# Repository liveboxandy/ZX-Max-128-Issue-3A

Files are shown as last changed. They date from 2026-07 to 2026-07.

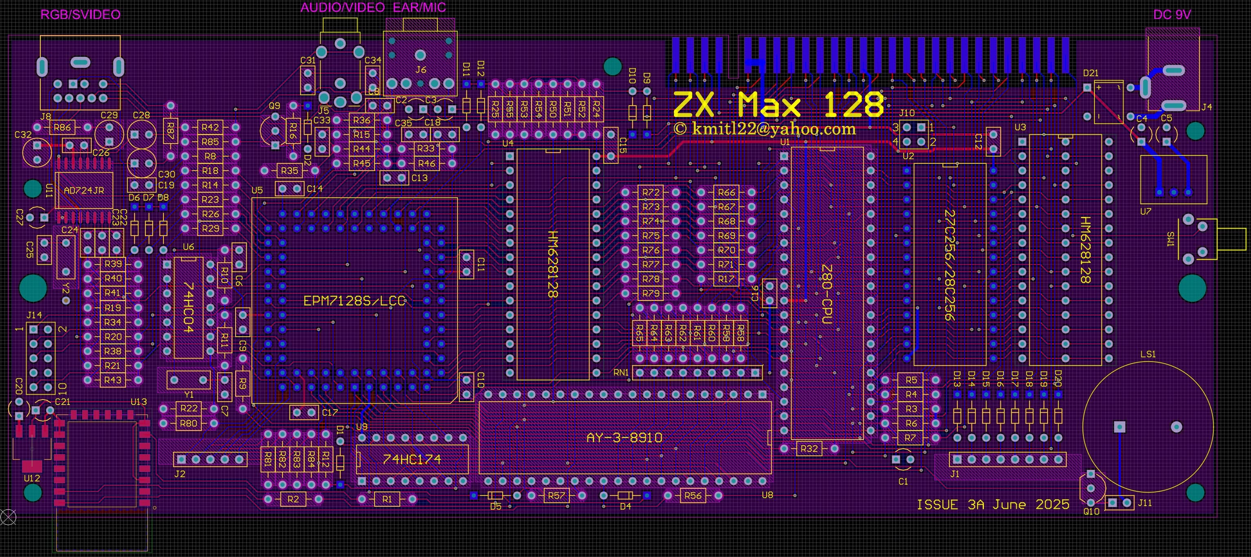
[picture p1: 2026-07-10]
ZX Max 128 Issue 3A June 2025.jpg

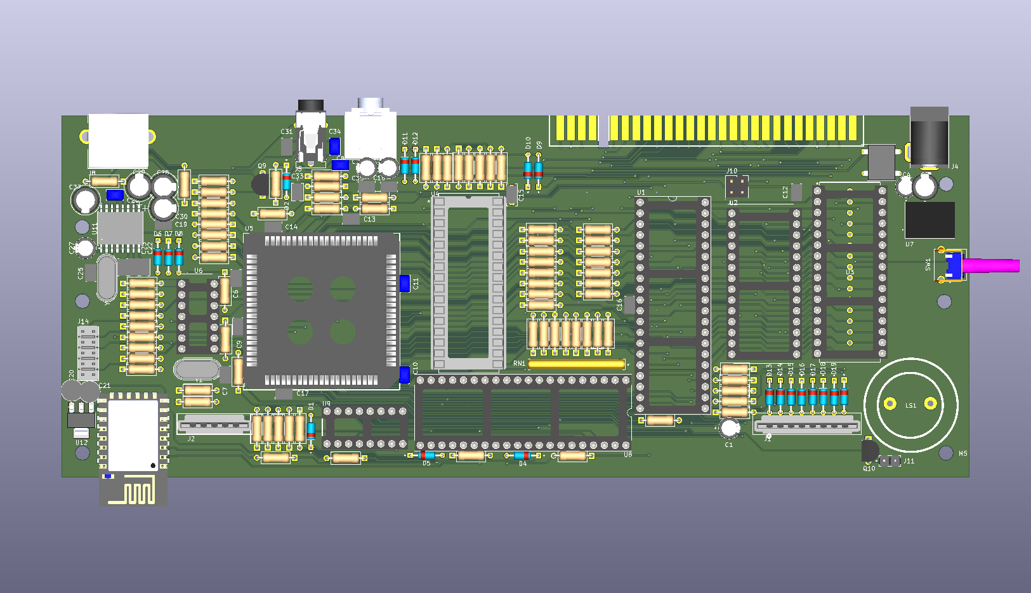
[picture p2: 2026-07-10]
ZX Max 128 Issue 3A PCB.png

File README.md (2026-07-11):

# ZX-Max-128-Issue-3A June 2025
KiCAD created files for the ZX Max 128 Issue 3A designed by DonSuperfo

This Kicad project has only been done so as to allow for a proper ibom that 
includes tracks and vias to be created.
I have tried to ensure that the footprints were located 
as close as possible to those in the original as well trying to follow 
the existing track and via locations. Some of the footprints that were 
downloaded from Digikey based on the parts in the official BOM do not fit 
exactly in their locations on the board. C15 is one example, I had to 
modify it's footprint to fit the pad dimensions. Some other capacitors also 
do not fit correctly but appear to be close enough.

As such, although I have tried to be as accurate as possible I would NOT 
use these gerbers to have a pcb manufactured without having another set of
eyes checking that the schematic that I have produced is correct to that 
produced by DonSuperfo and that the pcb data from Kicad reports no major errors 
with regards to copper tracing and via positions.

For the jumpers/connectors on the board,

J1 8 Way Keyboard Connector

J2 5 Way Keyboard Connector

J3 ZX Expansion Connector

J4 DC Input - can be any polarity. 

J5 Video is a TRRS, Tip-Video,RR-Left/Right, Screen-Ground.

J6 Ear/Mic. Wired as per ZX Spectrum 128K +3. TRS. Tip-Mic, Ring-Ear, Screen-Ground.

J7 Not Used

J8 SCART, mates with a Sega megadrive cable.

J9 Not Used

J10 EEPROM/UVEPROM selection, EEPROM 2-4/1-3, UVEPROM 2-1/4-3.

J11 Speaker On/Off

J12 Not Used

J13 Not Used

J14 JTAG for the EPM7128 wired as standard to an Altera device.

J15 Not Used

J16 Disable DivMMC, close = enable DivMMC, open = disable DivMMC or need to update program on U17

SW1 RESET

From information on the original website,

In order to make ACB output more balanced I would recommend following the -4.5dB 
panning law rule and make these updates:

R54, R55 = 470 Ohm
R51, R52 = 560 Ohm
R50, R53 = 330 Ohm

The ratio of 560 / 330 = 1.6969 is a close approximation of 1 / 10^(-4.5 / 20) = 1.6788. 
Also the resulting equivalent resistance is around 1000 Ohm which leads to less distortion on AY outputs.

mismatch between the value on the scheme and in the BOM for part R32 (INT)
on scheme it is 470R but in BOM 10k.
it looks like in BOM incorrect value.

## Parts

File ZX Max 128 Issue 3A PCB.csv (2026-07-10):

Source: | E:\Kicad\ZX Max 128 Issue 3\ZX Max 128 Issue 3 PCB.kicad_sch
Date: | 2026-07-10T17:57:36
Tool: | Eeschema 10.0.4
Generator: | C:\Program Files\KiCad\7.0\bin\scripting\plugins/bom_csv_grouped_by_value_with_fp.py
Component Count: | 162
Ref | Qnty | Value | Cmp name | Footprint | Description | Vendor | DNP
C1, C2, C3, C4, C20, C21, C27 | 7 | 10uF 25V | ECA-1EM100B | Mod:CAPPRD200W50D500H1100 | ECA-1EM100B - 10uF Aluminum Electrolytic Capacitors Radial
C5 | 1 | 22uF 16V | ECA-1EM100B | Mod:CAPPRD200W50D500H1100 | ECA-1EM100B - 10uF Aluminum Electrolytic Capacitors Radial
C6, C7 | 2 | 27pF | FG18C0G1H270JNT06 | Mod:CAPRB250W50L400T250H550
C8, C9, C10, C11, C12, C13, C14, C16, C17, C18, C22, C23, C24, C26, C31, C34 | 16 | 100nF | K104Z15Y5VF5TL2 | Mod:CAPRB250W50L400T250H550 | Vishay K 100nF Ceramic Multilayer Capacitor, 100 V dc, +85C, Y5V Dielectric, +80 %, -20 %
C15 | 1 | 100nF | K104Z15Y5VF5TL2 | Mod:Capacitor 3.8mm PItch | Vishay K 100nF Ceramic Multilayer Capacitor, 100 V dc, +85C, Y5V Dielectric, +80 %, -20 %
C19, C35 | 2 | 3n3 50V | K104Z15Y5VF5TL2 | Mod:CAPRB250W50L400T250H550 | Vishay K 100nF Ceramic Multilayer Capacitor, 100 V dc, +85C, Y5V Dielectric, +80 %, -20 %
C25 | 1 | 10pF | K104Z15Y5VF5TL2 | Mod:CAPRB250W50L400T250H550 | Vishay K 100nF Ceramic Multilayer Capacitor, 100 V dc, +85C, Y5V Dielectric, +80 %, -20 %
C28, C29, C30, C32 | 4 | 220uF 16V | 16YXJ220MT16.3X11 | Mod:CAP_YX_6P3X11_RUB
C33 | 1 | 10nF 50V | K104Z15Y5VF5TL2 | Mod:CAPRB250W50L400T250H550 | Vishay K 100nF Ceramic Multilayer Capacitor, 100 V dc, +85C, Y5V Dielectric, +80 %, -20 %
D1, D2, D4, D5, D6, D7, D8, D9, D10, D11, D12, D13, D14, D15, D16, D17, D18, D19, D20 | 19 | 1N4148 | 1N4148 | Mod:DIOAD753W49L380D172B | Diode 1N4148
D21 | 1 | DF02M | DF02M | Mod:DIP825W58P510L832H543Q4N | Bridge Rectifier DF02M 1A
J1 | 1 | 8 Pin FFC Connector | 5-520315-8 | Mod:55203155 | Connector FFC Socket 8 Pin
J2 | 1 | 5 Pin FFC Connector | 5-520315-5 | Mod:55203155 | Connector FFC Socket 5 Pin
J3 | 1 | ZX_48K_EDGE | ZX_48K_EDGE | Mod:ZX_BUS_B_TOP | ZX Spectrum 48K Edge Connector
J4 | 1 | PJ-002A | PJ-002A | Mod:CUI_PJ-002A
J5 | 1 | AV Jack | AudioJack3 | Mod:PJ-322A | AV Jack PJ-322
J6 | 1 | Connector Audio 3525N | SJ1-3525N | Mod:CUI_SJ1-3525N | Connector Audio 3525N
J8 | 1 | Connector 9 Pin Mini DIN | KMDGX-9S-BS-1 | Mod:KMDGX9SBS1 | Connector 9 Pin MiniDin
J10 | 1 | Conn_02x02_Odd_Even | Conn_02x02_Odd_Even | Connector_PinHeader_2.54mm:PinHeader_2x02_P2.54mm_Vertical | Generic connector, double row, 02x02, odd/even pin numbering scheme (row 1 odd numbers, row 2 even numbers), script generated (kicad-library-utils/schlib/autogen/connector/)
J11 | 1 | CON2 | M20-9990246 | Mod:HARWIN_M20-9990246 | Header 2x1
J14 | 1 | Header 5x2 | 10129381-910002BLF | Mod:AMPHENOL_10129381-910002BLF | Header 5x2
LS1 | 1 | Speaker | Speaker | Mod:Speaker | Speaker
Q9, Q10 | 2 | Transistor BC548 | BC548BTA | Mod:BC548BTA
R1, R2, R7, R9, R12, R32, R36, R56, R57, R58, R59, R60, R61, R62, R63, R64, R65, R66, R67, R68, R69, R70, R71, R72, R73, R74, R75, R76, R77, R78, R79 | 31 | 470R | CF14JT470R | Mod:STA_CF14_STP | 470R
R3, R4, R5, R6, R15, R16, R24, R25, R35, R45, R80, R81, R82, R83, R84 | 15 | 10K0 | CF14JT10K0 | Mod:STA_CF14_STP | Resistor 10K0
R8 | 1 | 2K70 | CF14JT2K70 | Mod:STA_CF14_STP | 2K70
R10 | 1 | 1M00 | CF14JT1M00 | Mod:STA_CF14_STP | 1M00
R11, R50, R53, R54, R55 | 5 | 1K00 | CF14JT1K00 | Mod:STA_CF14_STP | 1K00
R14, R18, R23, R26, R29 | 5 | 68R0 | CF14JT68R0 | Mod:STA_CF14_STP | 68R0
R17, R22 | 2 | 4K7 | CF14JT4K70 | Mod:STA_CF14_STP | 4K70
R19, R20, R21, R34, R38, R43 | 6 | 150R | CF14JT150R | Mod:STA_CF14_STP | 150R
R33 | 1 | 33K0 | CF14JT33K0 | Mod:STA_CF14_STP | 33K0
R39, R40, R41, R42, R86, R87 | 6 | 75R0 | CF14JT75R0 | Mod:STA_CF14_STP | 75R0
R44, R46 | 2 | 150K | CF14JT150K | Mod:STA_CF14_STP | 150K
R51, R52 | 2 | 2K20 | CF14JT2K20 | Mod:STA_CF14_STP | 2K20
R85 | 1 | 470K | CF14JT470K | Mod:STA_CF14_STP | 470K
RN1 | 1 | 10K | 4609X-101-103LF | Mod:SIP249W50P254L2281H508Q9
SW1 | 1 | Switch 6x6 RA | 2-1825027-0 | Mod:SW2_1825027-G_TEC
U1 | 1 | Z80 | Z84C0010PEG | Mod:Z80_Socket | Z80 CPU
U2 | 1 | EEPROM/EPROM 32Kx8 | AT27C256R-45PU | Mod:DIP1556W56P254L3702H483Q28N | EEPROM/EPROM 32Kx8
U3 | 1 | AS6C1008-55PCN | AS6C1008-55PCN | Mod:U3
U4 | 1 | AS6C1008-55PCN | AS6C1008-55PCN | Mod:PDIP-32_MIL600_ALL
U5 | 1 | EPM7128SLC | PLCC-84-AT | Mod:PLCC84AT | EPM7128SLC-84 PLCC Socket
U6 | 1 | 74HC04 | 74HC04_1 | Mod:DIP794W53P254L1930H508Q14N | Hex Inverter
U7 | 1 | R-78E5.0-1.0 | R-78E5.0-1.0 | Mod:CONV_R-78E5.0-1.0
U8 | 1 | AY-3-8910 | AY-3-8910 | Mod:Z80_Socket
U9 | 1 | SN74HC174N | SN74HC174N | Mod:DIP794W53P254L1930H508Q16N | Hex D flip-flop w/reset,SN74HC174N DIP16
U11 | 1 | AD724JRZ | AD724JRZ | Mod:RW_16_ADI | RGB - PAL Encoder
U12 | 1 | 3V3 1Amp | AZ1117IH-3.3TRG1 | Mod:SOT230P700X185-4N | Voltage Regulator 3V3 1Amp
U15 | 1 | ESP8266-12E | ESP8266-12E | Mod:WIFI_Module_ESP8266_12E | ESP8266-12E Bluetooth Module
Y1 | 1 | 28.375Mhz | Crystal | Mod:Crystal_HC49-4H_Vertical | Two pin crystal
Y2 | 1 | 4.433Mhz | Crystal | Mod:Crystal_HC49-4H_Vertical | Two pin crystal

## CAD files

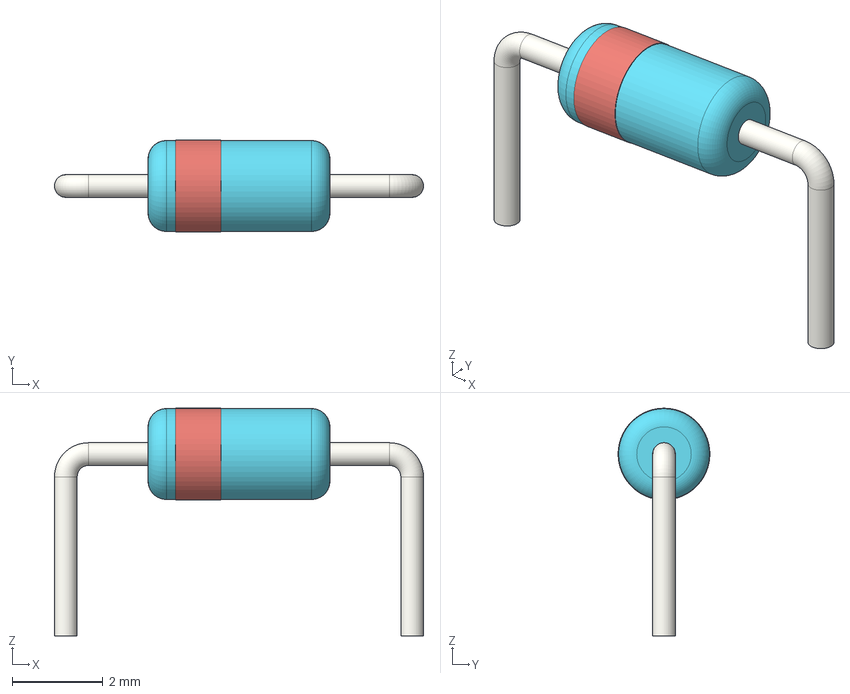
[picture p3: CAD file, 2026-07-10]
Step/D_DO-35_SOD27_P7.62mm_Horizontal.step
8.12 x 2.02 x 5.01 mm

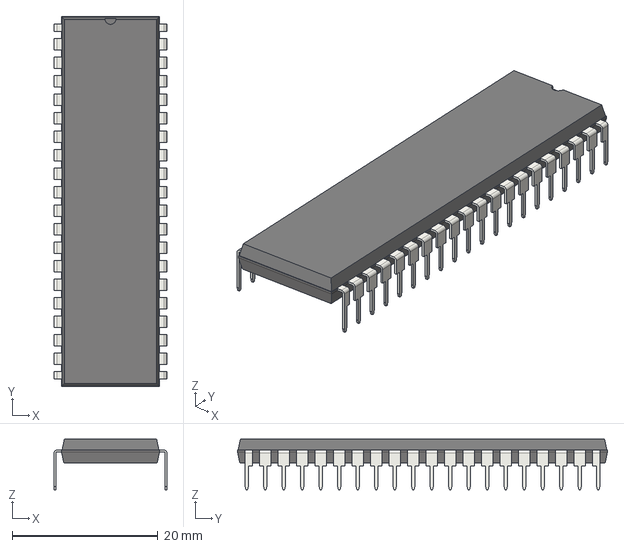
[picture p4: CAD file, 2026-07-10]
Step/DIP-40_W15.24mm.step
15.5 x 50.8 x 6.98 mm

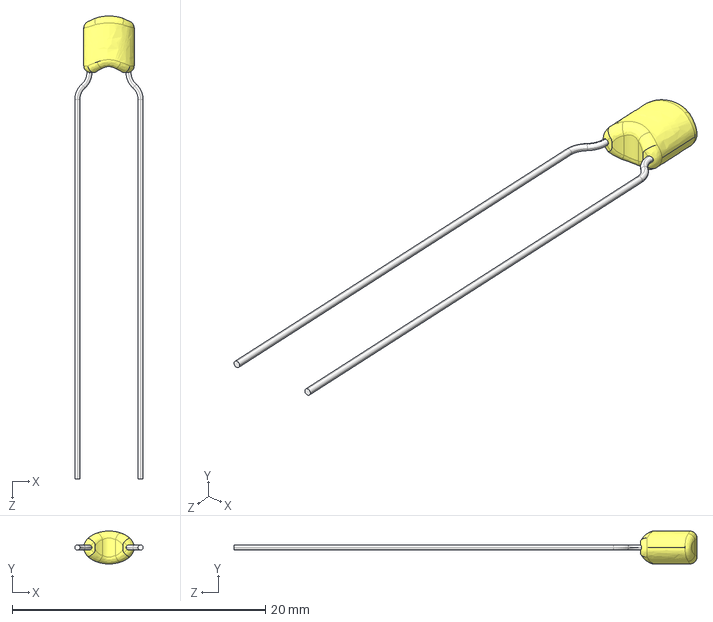
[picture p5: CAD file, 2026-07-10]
Step/Capacitor 100nF 50V MLCC K104Z15Y5VF5TL2.stp
5.40 x 2.60 x 36.6 mm

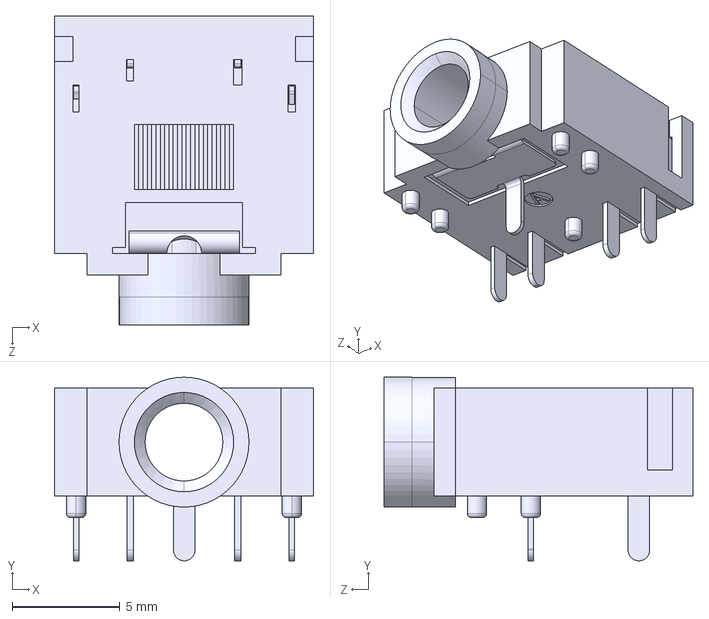
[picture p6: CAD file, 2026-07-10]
Step/Audio Connector SJ1-3525N.step
12.0 x 8.51 x 14.3 mm

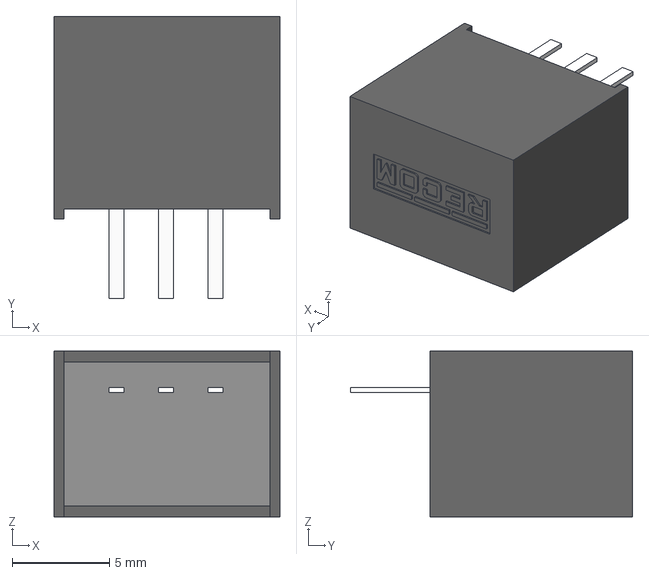
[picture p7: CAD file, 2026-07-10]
Step/R-78E5.0-1.0.step
11.6 x 14.5 x 8.50 mm

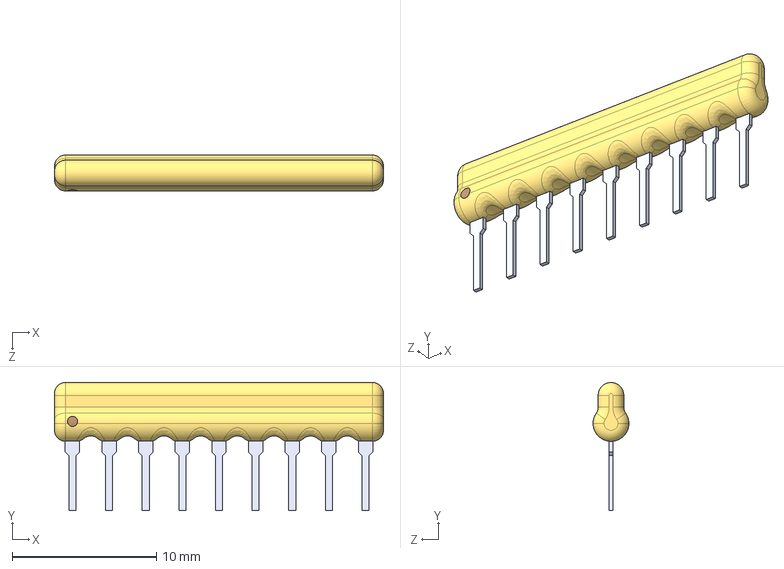
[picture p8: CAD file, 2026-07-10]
Step/RNET 10K 9PIn 4609X-101-103LF.step
22.8 x 8.88 x 2.49 mm

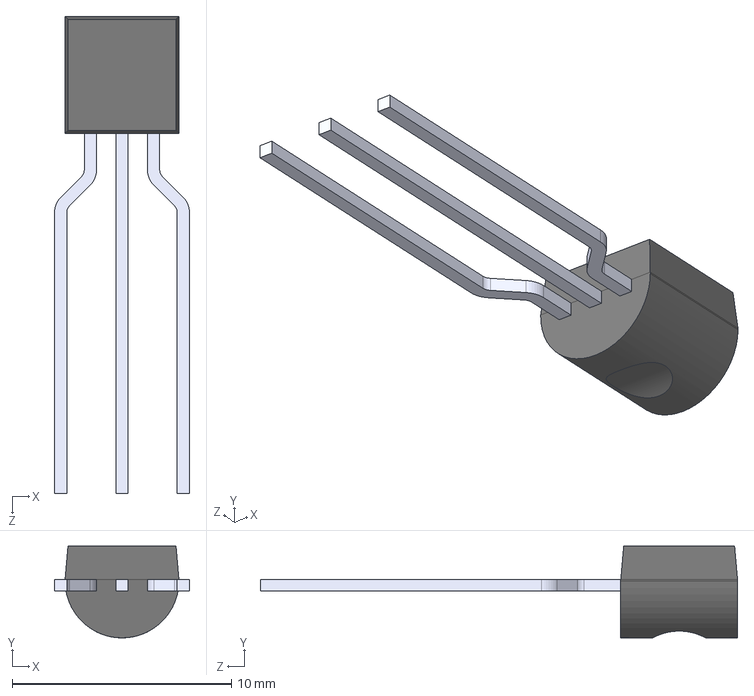
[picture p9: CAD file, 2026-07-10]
Step/Transistor BC548BTA.stp
6.16 x 4.19 x 21.8 mm

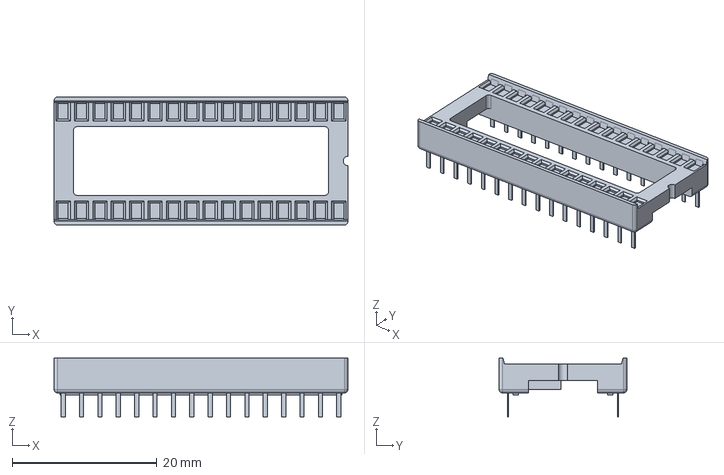
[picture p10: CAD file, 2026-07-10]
Step/DIP-32_W15.24mm_Socket-1.stp
40.6 x 17.7 x 8.10 mm

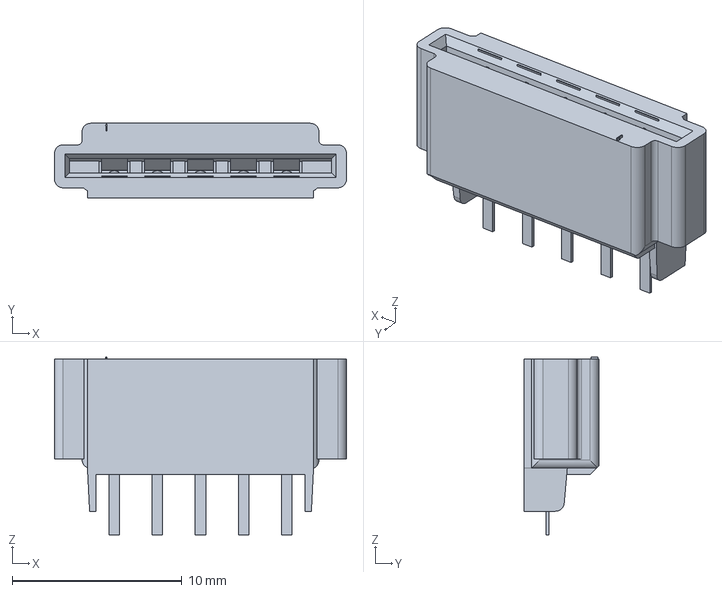
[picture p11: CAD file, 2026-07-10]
Step/Connector 5 Way Keyboard CONN_5-520315-5.stp
17.2 x 4.39 x 10.5 mm

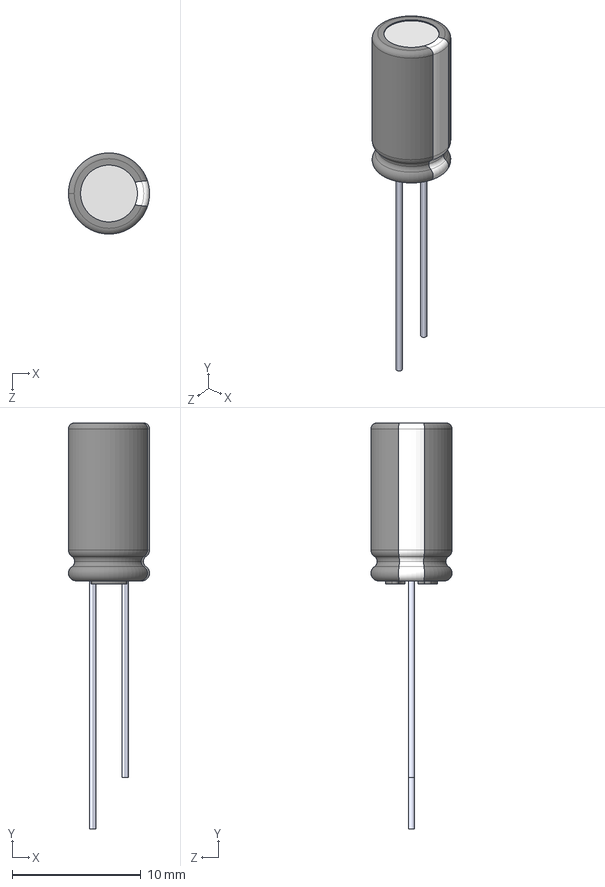
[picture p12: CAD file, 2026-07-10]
Step/16YXJ220MT16.3X11.step
6.30 x 31.5 x 6.30 mm

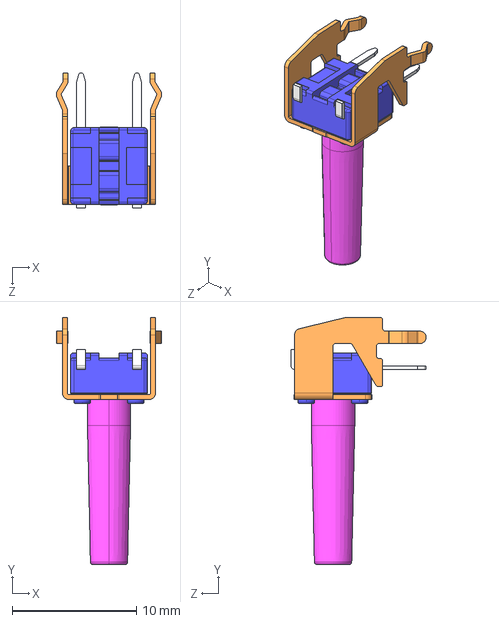
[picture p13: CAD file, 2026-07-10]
Step/Switch 6mm RA SKHHNHA010.stp
8.50 x 19.9 x 10.9 mm

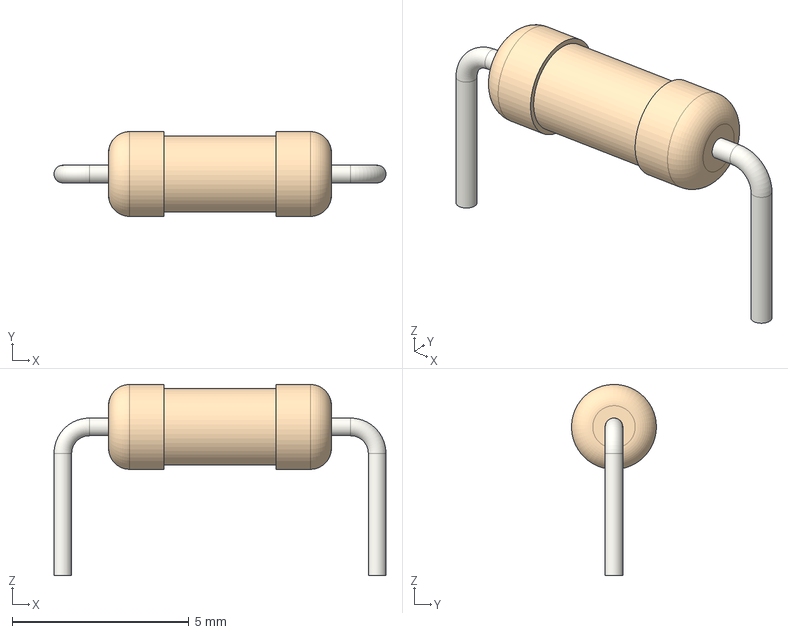
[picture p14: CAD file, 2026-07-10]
Step/Resistor.08.88.step
9.38 x 2.40 x 5.40 mm

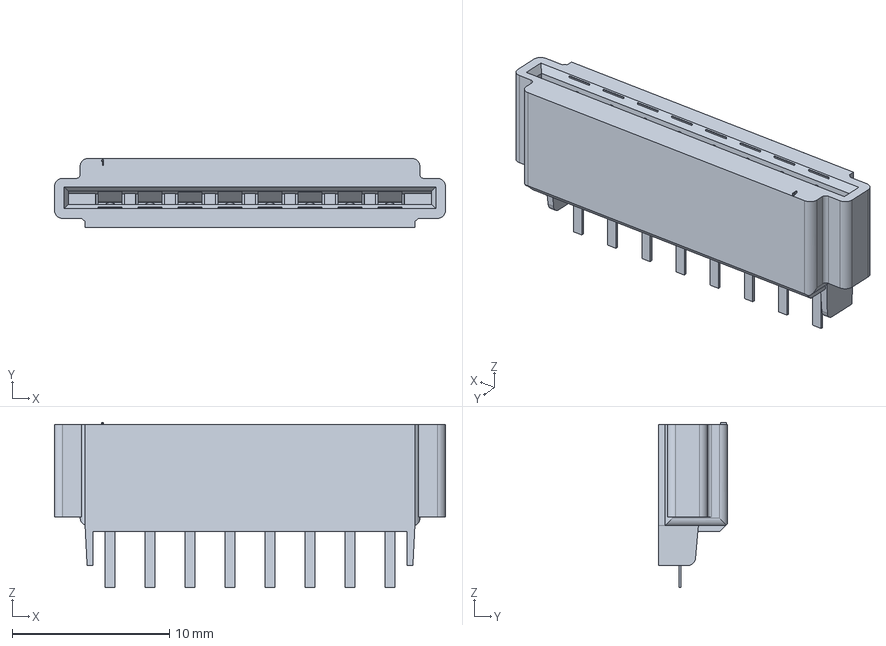
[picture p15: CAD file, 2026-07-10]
Step/CONN_5-520315-8_TYC.stp
24.8 x 4.39 x 10.5 mm

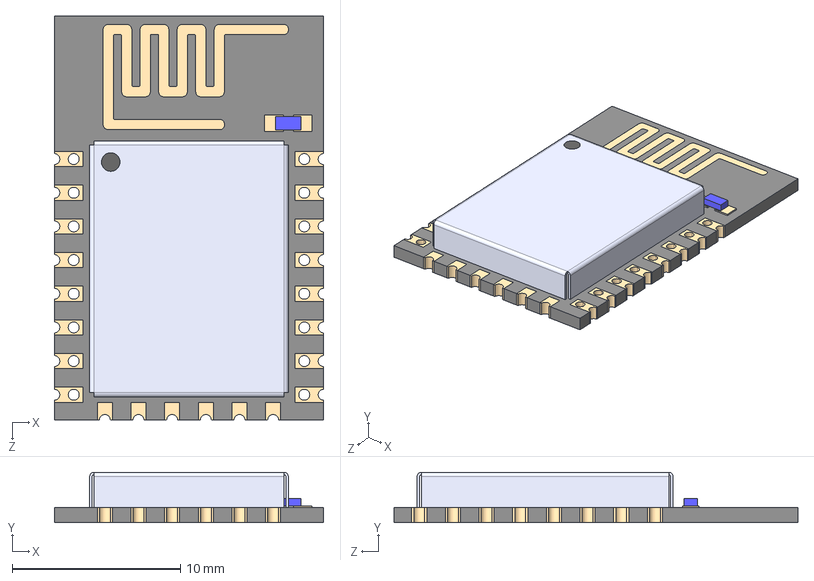
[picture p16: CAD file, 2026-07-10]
Step/ESP8266-12E_ESP-12E.step
16.0 x 3.00 x 24.0 mm

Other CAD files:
Step/DIP-16_W7.62mm_Socket.step
Step/DIP-14_W7.62mm_Socket.step
Step/DF02M.stp
Step/10129381-910002BLF.step
Step/9Pin MiniDIN KMDGX-9S-BS-1.stp
Step/9Pin MiniDIN KMDGX-9S-BS-1_A1.IGS
Step/ADI724JRZ RW_16_ADI.step
Step/AS6C6264-55PCN.stp
Step/AT27C256R-45PU.stp
Step/Capacitor 100pF 50V MLCC K101J15C0GF53L2.stp
Step/Capacitor 10nF 100V MLCC FA18C0G2A103JRU06.step
Step/Capacitor 10uF 25V ECA-1EM100B.stp
Step/Capacitor 22uF 16V 5x7 EEAGA1C220H.step
Step/Connector Pin-Pin 1x2 M20-9990246.step
Step/DIP-14_W7.62mm.step
Step/DIP-16_W7.62mm.step
Step/DIP-28_W15.24mm.step
Step/DIP-28_W15.24mm_Socket.step
Step/DIP-32_W15.24mm.step
Step/DIP-32_W15.24mm_Socket.step
Step/DIP-40_W15.24mm_Socket.step
Step/Header 5x2 Pin-Pin 10129381-906002BLF.step
Step/PJ-002A.step
Step/PJ-322.step
Step/PLCC-84-AT.stp
Step/Voltage Regulator AZ1117IH-3.3TRG1.step

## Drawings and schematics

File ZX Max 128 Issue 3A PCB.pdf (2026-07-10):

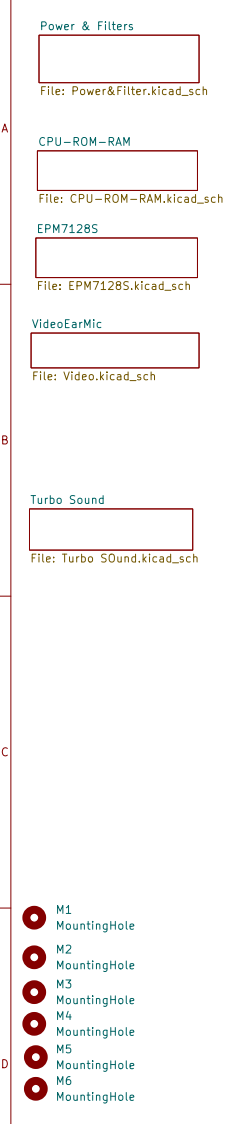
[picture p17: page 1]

Power & Filters File: Power&Filter.kicad_sch CPU-ROM-RAM
File: EPM7128S.kicad_sch M3 MountingHole M6 MountingHole M4 MountingHole M2 MountingHole M5 MountingHole M1 MountingHole

File: CPU-ROM-RAM.kicad_sch

Sheet: /
File: ZX Max 128 Issue 3 PCB.kicad_sch
Title:

Size: A4 | Rev:
KiCad E.D.A. 10.0.4 | Id: 1/6

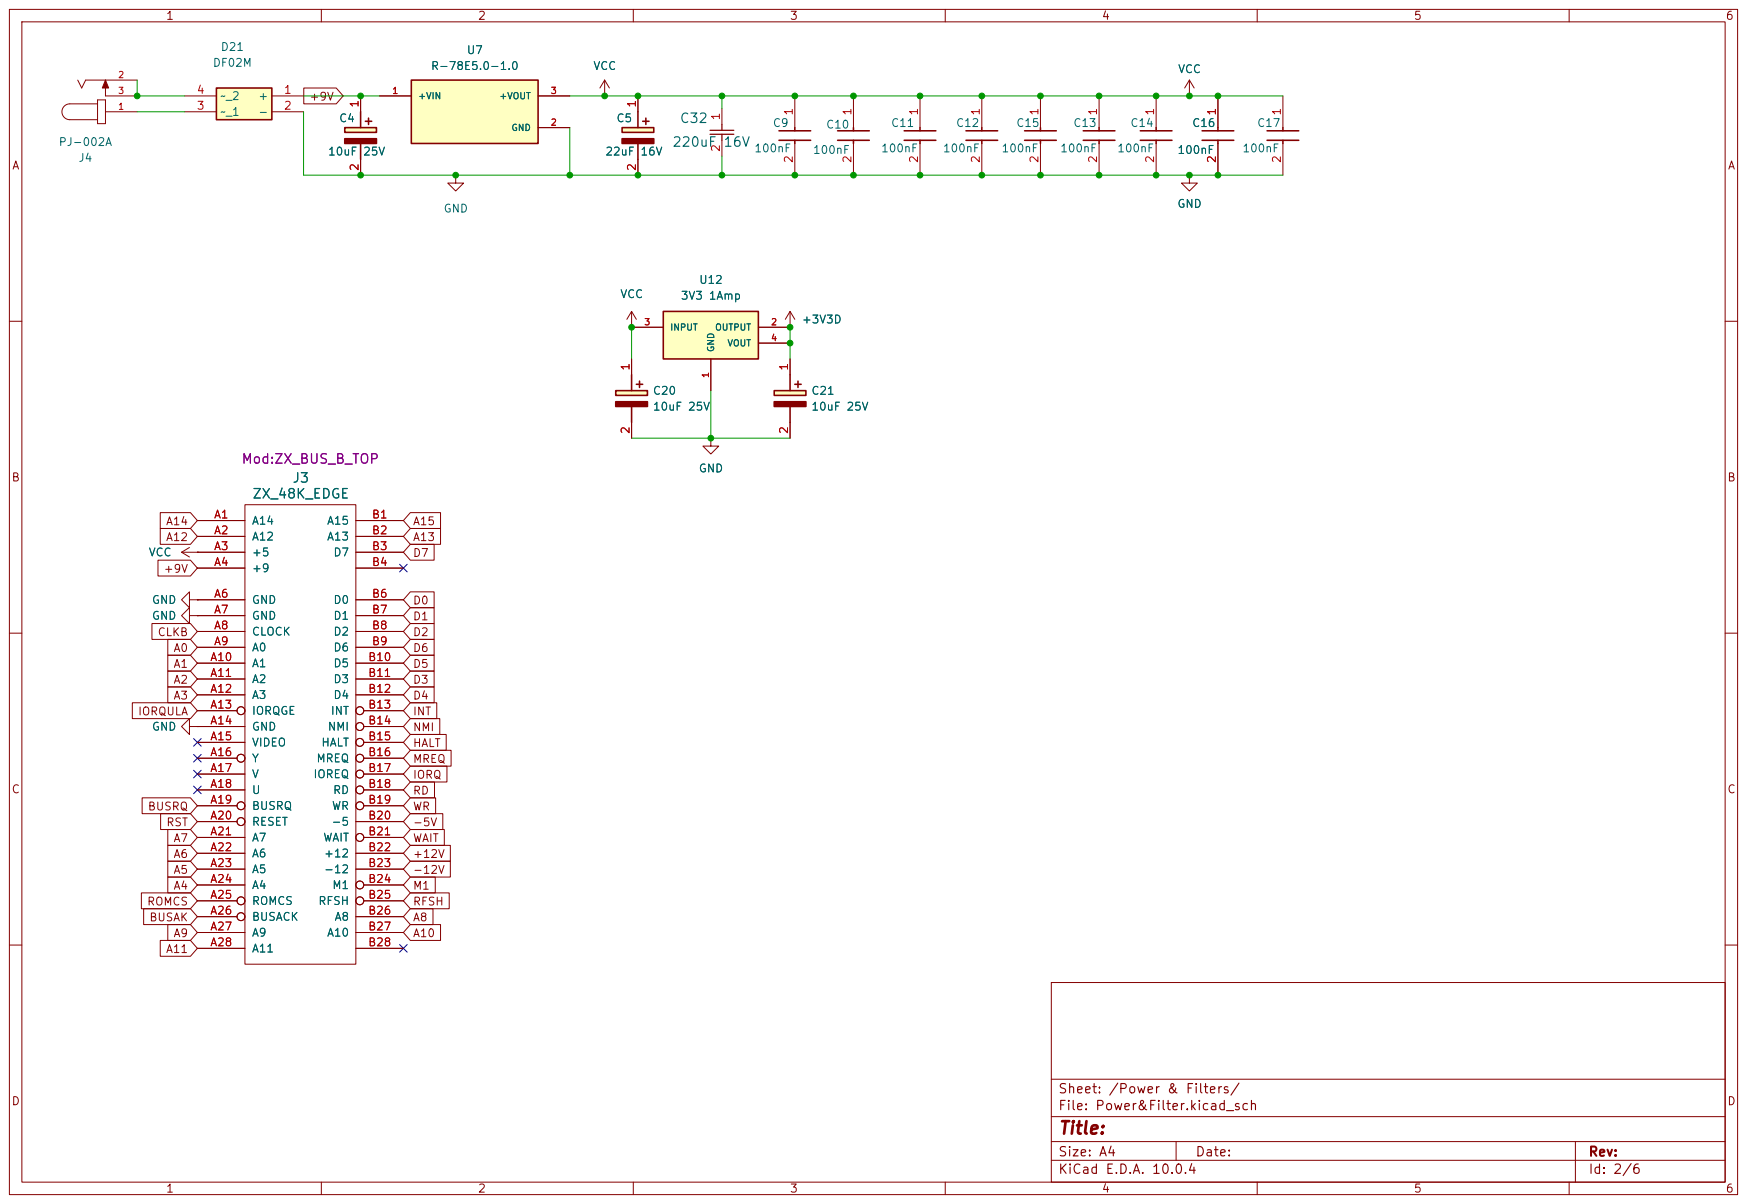
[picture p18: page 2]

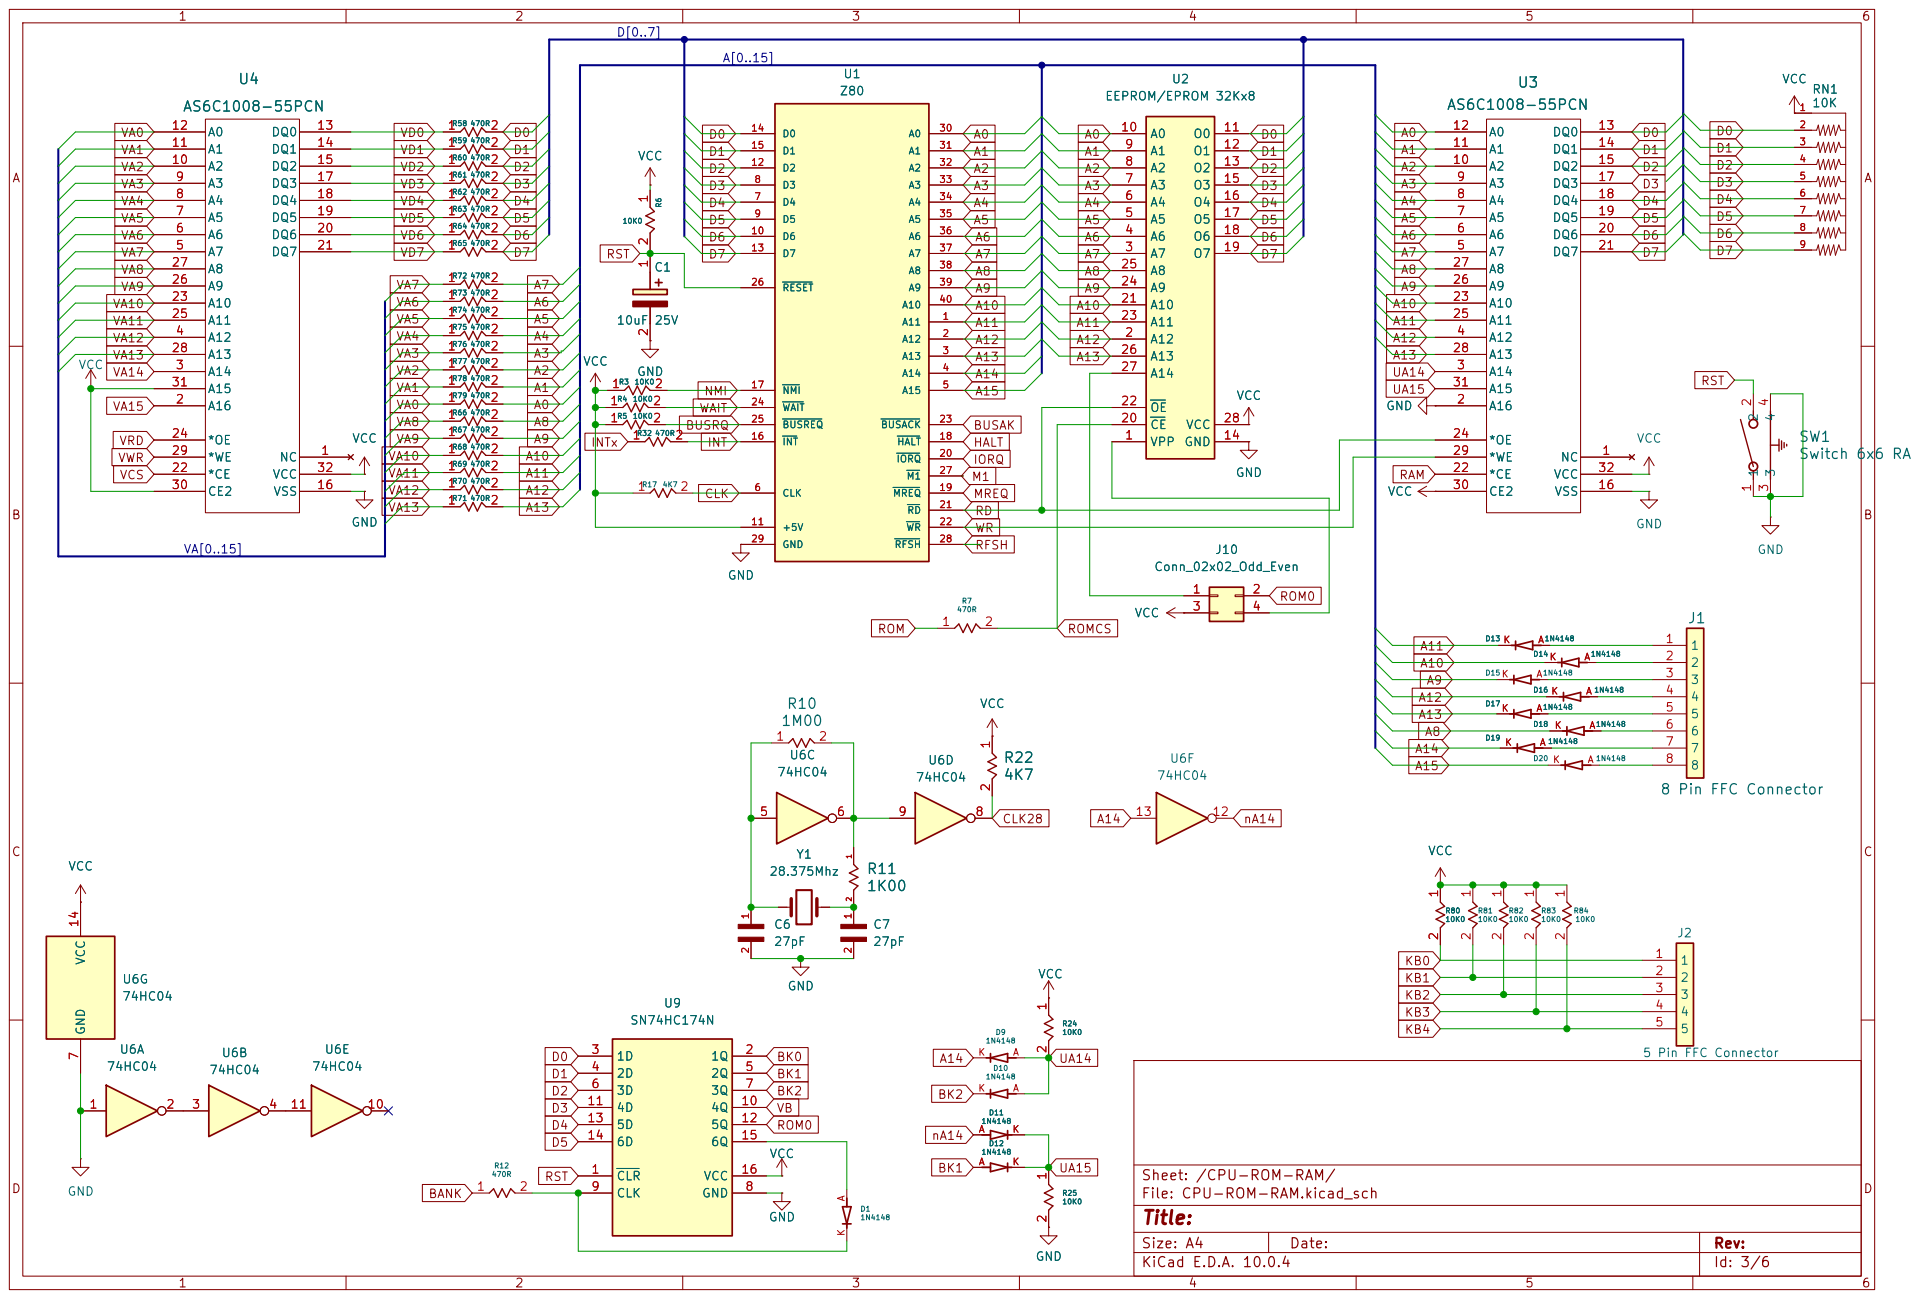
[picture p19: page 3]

U1 Z80 Z80 | EEPROM/EPROM 32Kx8

GND
8 Pin FFC Connector GND

Sheet: /CPU-ROM-RAM/
File: CPU-ROM-RAM.kicad_sch
Title:

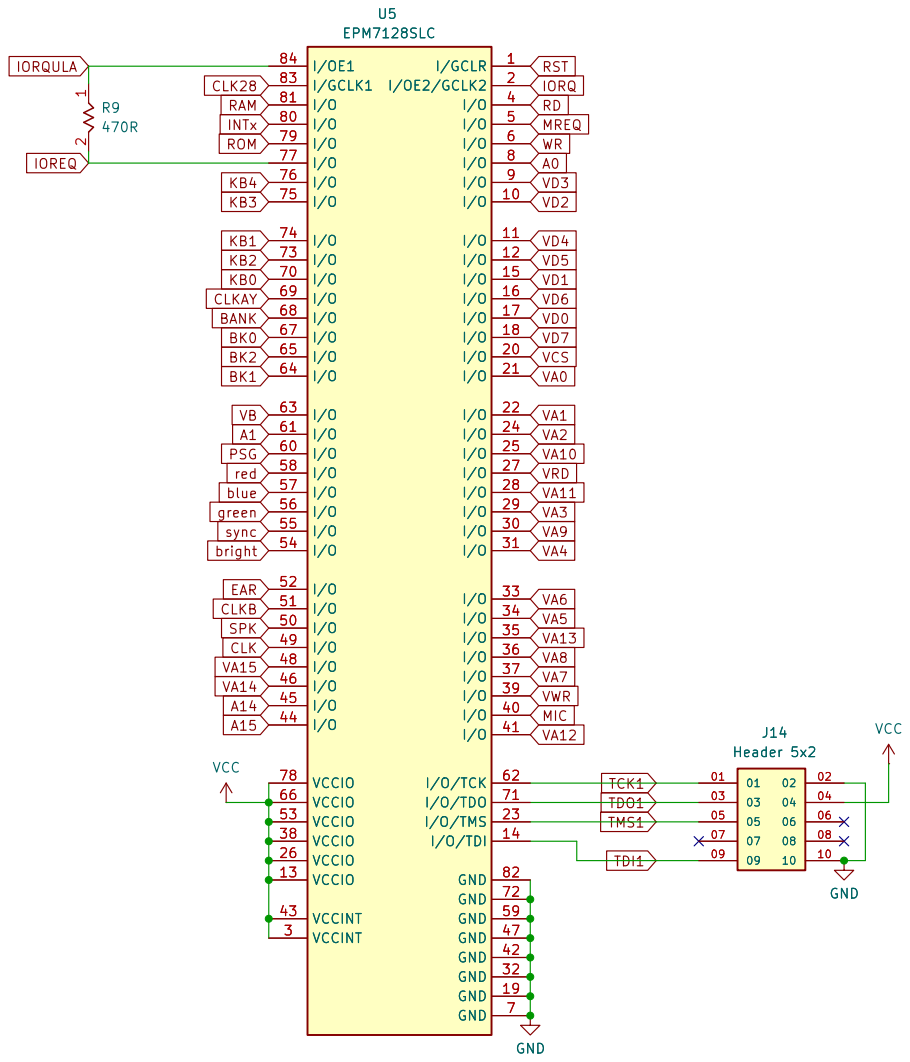
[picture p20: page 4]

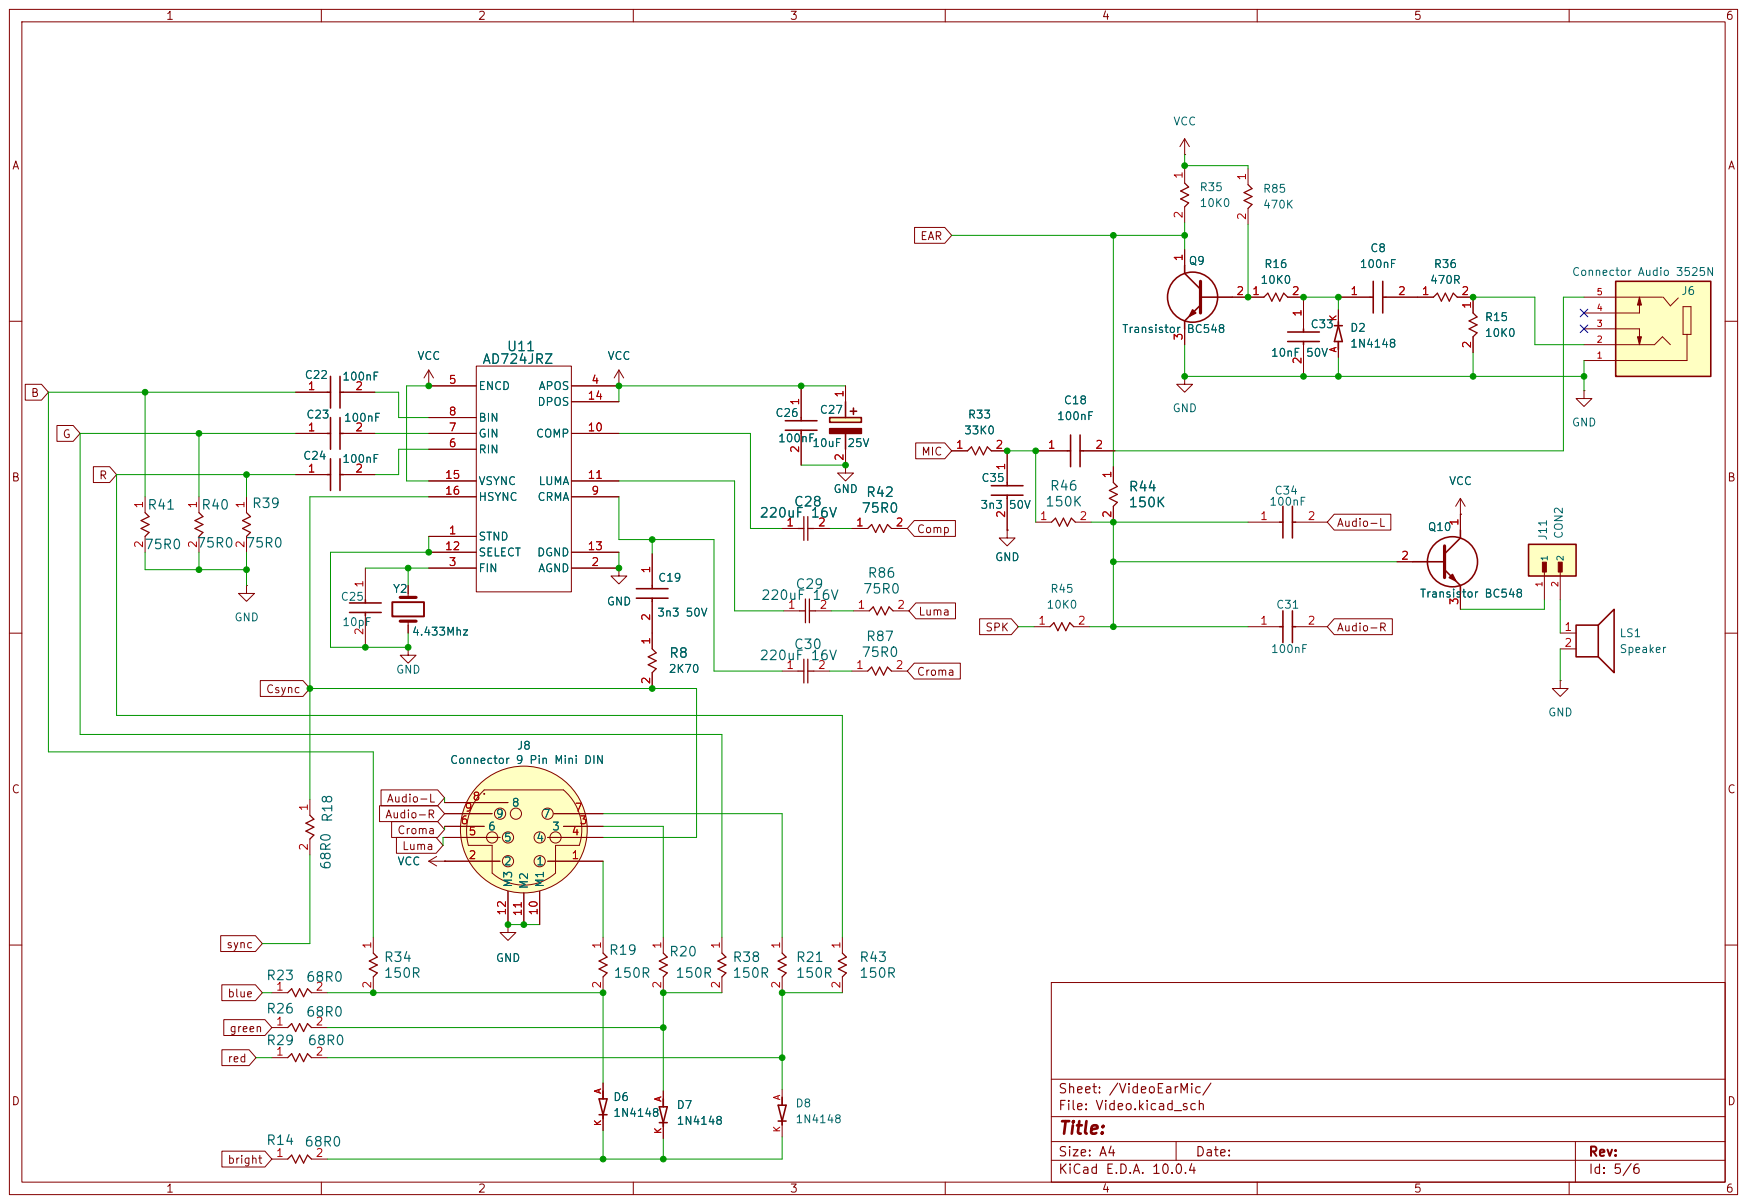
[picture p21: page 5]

J8 Connector 9 Pin Mini DIN

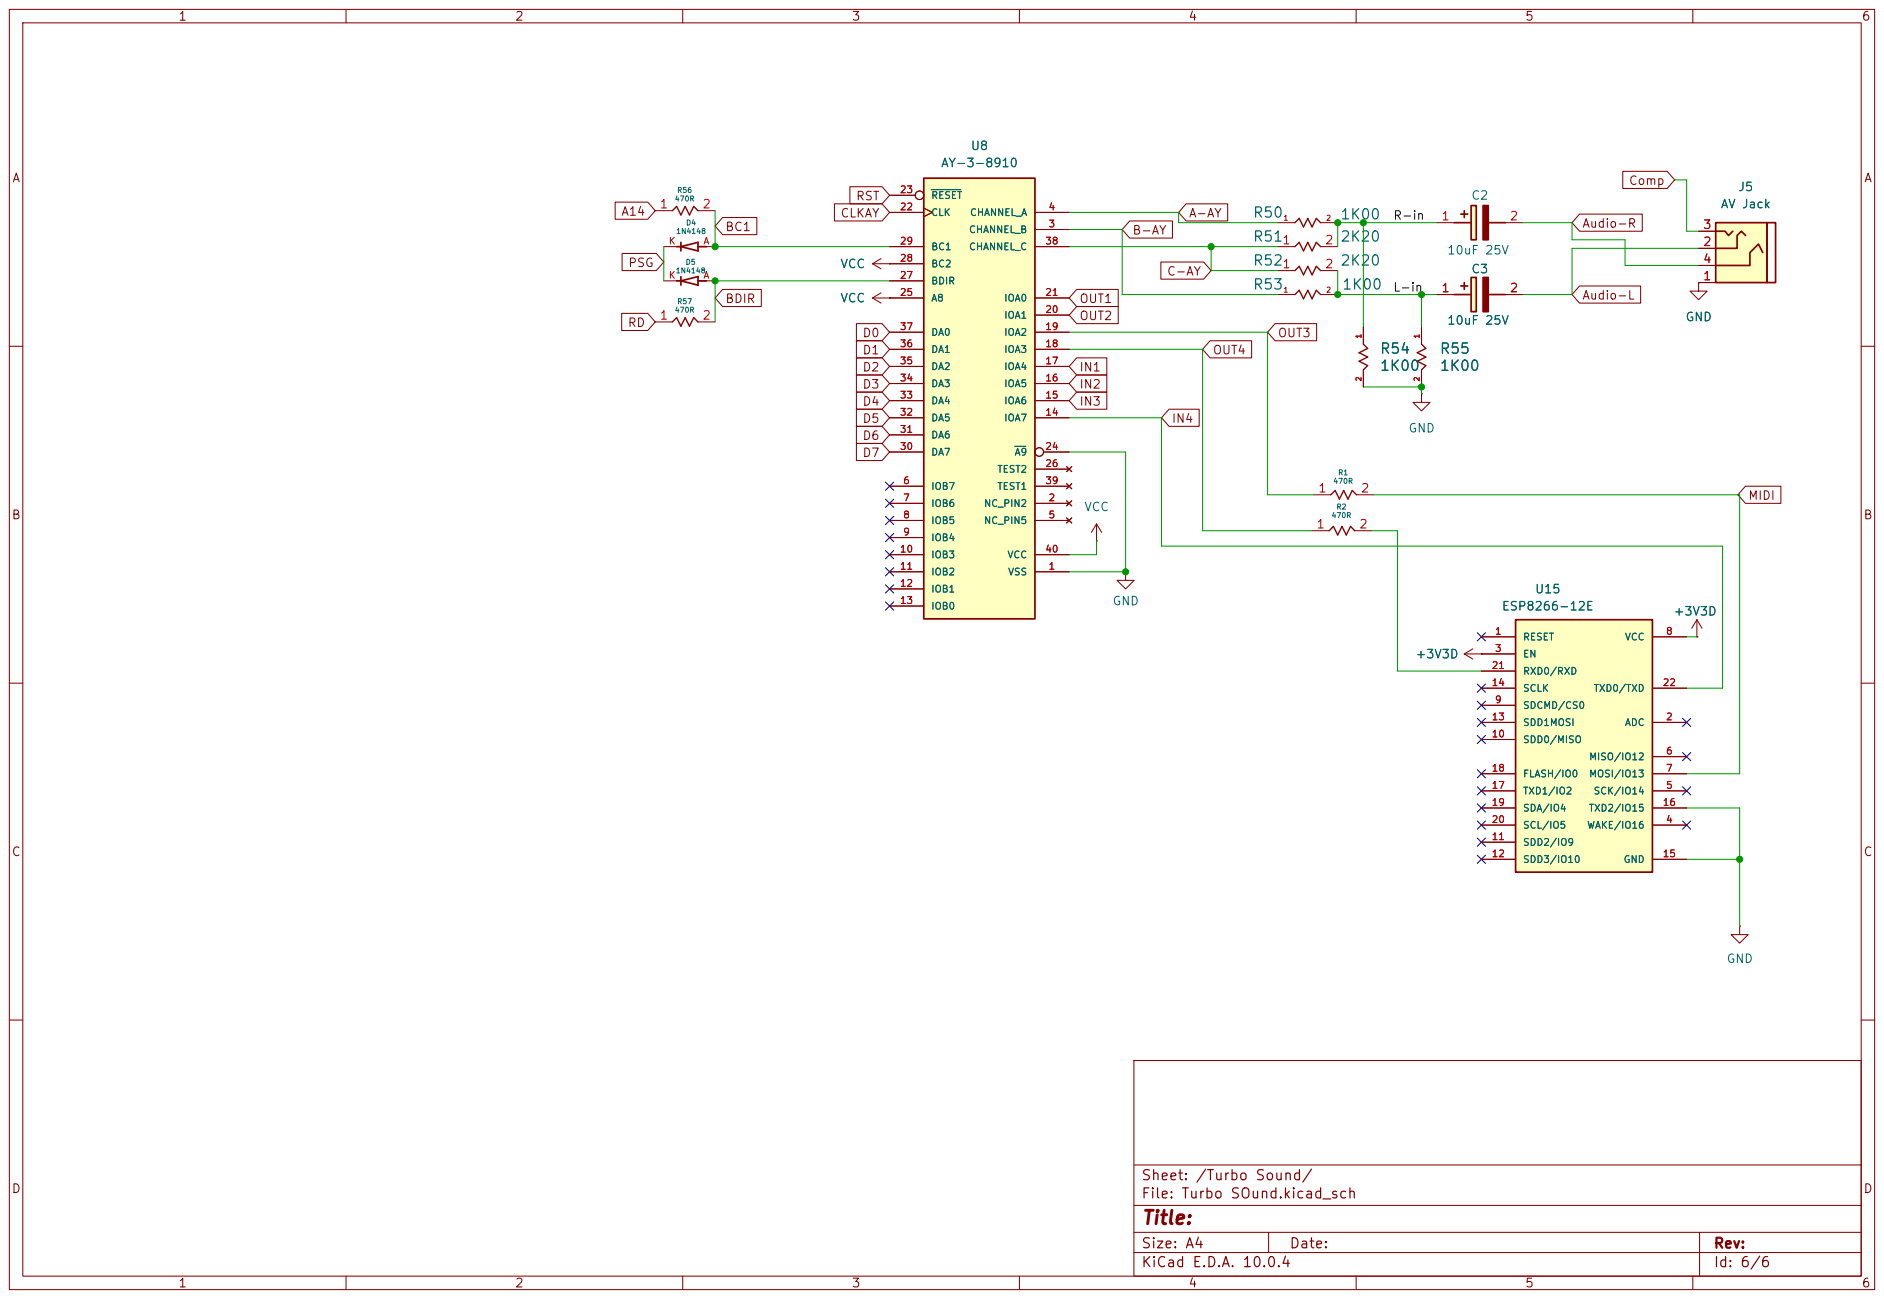
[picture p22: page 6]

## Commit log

2026-07-10 Enhance README with project details and warnings
    Added detailed project information, including warnings about accuracy and specific jumper/connectors on the board. Updated resistor recommendations for balanced ACB output.
2026-07-10 Add files via upload
    Initial Release
    [10129381-910002BLF.step, 16YXJ220MT16.3X11.step, 5-520315-5.stp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]
2026-07-10 Enhance README with jumper/connectors details
    Added detailed descriptions for jumpers/connectors on the board.
2026-07-26 Revise README for clarity on assembly and parts
    Updated README to clarify assembly instructions and part compatibility.

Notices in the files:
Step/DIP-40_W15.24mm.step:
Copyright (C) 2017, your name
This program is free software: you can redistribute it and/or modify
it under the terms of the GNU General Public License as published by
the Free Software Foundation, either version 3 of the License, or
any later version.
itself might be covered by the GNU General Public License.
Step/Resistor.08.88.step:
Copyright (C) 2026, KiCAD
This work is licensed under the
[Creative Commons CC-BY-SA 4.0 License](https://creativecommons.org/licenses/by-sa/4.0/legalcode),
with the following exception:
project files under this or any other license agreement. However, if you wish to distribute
